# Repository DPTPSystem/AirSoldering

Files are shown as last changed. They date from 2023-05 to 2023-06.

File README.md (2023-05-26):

# AirSoldering
* Forrólevegős SMD forrasztó állomás
* DPTP System 2023-05-24.
* Projekt keletkezése: 2014-05-16.
* 4 soros karakteres kijelző, PIC18F4550 és vagy PIC18F452, K típusú hőszenzor és MAX6675 - MPLAB IDE 8.91

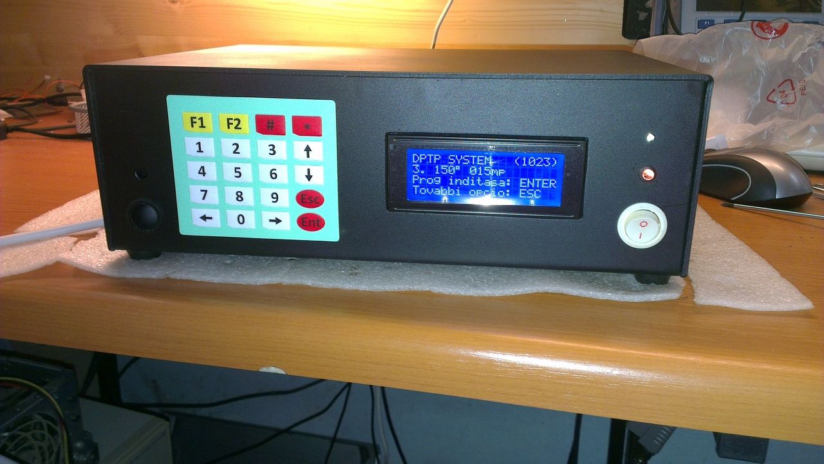
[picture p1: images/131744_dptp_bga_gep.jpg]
DPTP System BGA soldering


# A kezdet és figyelmeztetés
Anno 2014-ben kezdtem el komolyabban fogglalkozni a mikrokontrollerekkel és az azokra írható programokkal. Ezzel egyidőben az elektrokinával is 
fogglakoznom kellett mert a mikrokontrollerek önmagukban nem sokat érnek, kell egy jó elektronikai kialakítás mondhatni körítés, amely majd 
betölti azt a szerepet, amellyel a programunk képes a vezérlést elvégezni. Mivel a kezdet mindig nehéz és sok tanulással jár, sokáig nem készítettem
sematikus/kapcsolási rajzokat, szimplán elkészítettem fejből a nyáktervet és a nyáktervekre írtam fel az alkatrészek paramétereit. Amjd ezt használva
beültettem az elkészült panelekt. Ezért ez a projekt nem tartalmaz kapcsolási rajzot, viszont a nyákterven fel vannak tüntetve az alkatrészek
megnevezései. Az elkészült panel egyszerűsége olyan mértékű, hogy kis szakértelemmel nagyon könnyen át lehet látni. Kérek mindenkit, hogy ennek
tudatában álljon neki az utánépítésnek. Köszönöm.

# Miért
2005-ben megjelent Xbox360-as konzolok hirtelen, gyors és tömeges meghíbásodásai miatt, mondhatni kényszerhelyzetben egy prototípus gépen
kezdtünk el dolgozni, amely arra volt hivatott, hogy megoldja a BGA tokozott chippek házi körülmények közt történő ipari színtű javítását/cseréjét.
A BGA chippek cseréjéhez fontos volt egy alsó PCB és felső kimondottan a BGA chipekhez igazítható forrasztási mehanizmus megalkotásárára, így
született az első PID vezérlésű saját forrasztó államásunk, amellyel talán az országban elsőként kezdük el az Xbox360-as konzolok tömeges javítását.
Ezt követően a rengeteg tapsztalatra és a fejlődő tudásunkra támaszkodva készítettük el az ebben a szálban megosztott forrólevegős, hőprofilos
forrasztó berendezés terveit és programját.

# Célok
A célunk az volt, hogy a kisebb BGA tokozású, de akár SMD alkatrészeket, hőprofilt alkalmazva, optimális a lehető legkisebb hőstressz melett
legyünk képesek a javításokat elvégezni, BGA alkatrészeket cserélni. Fontos volt számunkra, hogy úgy tudjunk a javításokat végezni, hogy közben
a tapasztalatainkra tudjunk támaszkodni és ennek megfelelően a már kitesztelt és jól bevált hőprofilok mellett a lehető legkisebb károsodással
járjanak a kényes berenezések esetén is a beavatkozások.

# Elmélet a megoldás
A rendszer elméleti és egyben a megoldása is a sikeres utánépítésnek, hogy valamelyest képet alkossak arról, hogy milyen további eszközöket kell 
beszerezned, hogy megfelelő írányba indulhass el. Hogy mi a jó és mi nem azt nem akarom senkinek megírni, de hogy én milyen alkotó elemeket
használtam fel azt nyugodtan tudom leírni. 9 fő részre osztható a teljes állomás:
1. aluminium doboz, mérete függ majd a légszállítást végző ventillűtor méretétől.
2. légszállításra PWM vezérelhető 12v-os ventillátor (PS3 ventillátor, ~1.5A).
3. 3D nyomtatott vagy valamilyen kialakítással meg kell oldani a megfelelő légcsatornát
4. 4soros, karakteres kijelző HD44780
5. K-type sensor (80-100cm) vagy forrólevegős forrasztó fej, amelyben benne van a K-type szenzor
6. 12v-os kapcsolóüzemű tápegység. (fontos, hogy ipari vagy jó minőségú legyen, ne legyen zajos)
7. 4x4-es matrix gombsor, billenő bekapcsoló gomb, USB kimenet (opcionális)
8. 45A-es logikai szilárdtestrelé 600v-os (fűtőszál kapcsolgatására)
9. Buzzer (csipogó)

Elméleti működés: A gép billenő kapcsolóval felkapcsólva az előre elmentett hőprofilt betölti és várakozik a felhasználóra. A memória és a MAX6675
SPI kapcsolaton keresztül kommunikál. A memóriába összesen 15, egyenként hat lépésben megadott hőprofilt lehet elmenteni, amelyet egy menüből
később el lehet érni illetve be lehet tölteni. Minden betöltésnél automatikusan a PIC EEPROM memóriájába lementni a betöltött profil számát, amely
a memóriában lévő pozicióját határoza meg. Indulásnál ezt az EEPROM területet vizsgálja a program és ennek megfelelően tölti be az utoljára kiválasztott
profilt. Az eszközön 3 LED is található. Rendserint ezek különböző színűek, az egyik LED az üzemelést hivatott jelezni ez álltalában piros, a második
egy kék színű LED, amely a fejben lévő fűtőszál üzemidejét jelzi vissza. A harmadik LED egy villogó sárga vagy piros visszajelző a teszt vagy 
demó programot mutatja, amely majd egyszer az SMD forrasztás programmódja lesz. (egyszer)
A kezelőfelületnél mindenki eldöntheti mit mire használ, csak ebben az esetben a programban ezen részeket át kell írni, de úgy vélem a lehető 
legoptimálisabb és kézenfekvő funkciókat tettem a gombokra, amelyeket a kijelzőn jelzek is.
A MAX6675 egy K típusú szenzorhoz készült analog digitális converter, amely az alapvető kompenzációkat tartalmazza, és 12bit-es digitális jelre alakítja,
amelyekhez SPI-vel lehet hozzáférni. A PWM vezérlés a légáramlat függvényében adható meg figyelembe véve, a forrasztófejre helyzett szűktést.
A hőprofil elindulását követően 4 fontos értéket láthatunk a kijelzőn. Felüle a beállított hőmérségklet és idő látható, alattuk pedig az aktuális
adatokat írja ki. A programot bármikor meg lehet szakítani, majd azt újra indítani vagy módosítani a szerkesztés menüponton keresztül. Fontos lehet
megemlítenem, hogy a 4x4-es gombsort egy saját elképzelés alapján megírt program vezérli, amely a régi telefonoknál (NOKIA) megszokott SMS írásainál
hazsnálhattunk. Szöveg beírását követően fel fogja kínálni a lehetőségeket a program. A beírásnál elég jól sikerült behatárolnom és kitesztelnem az 
elkövethető direkt vagy véletlen hibákat, így a program majd ennek megfelelően korrígál. A megszakításokat kimértem, így az 1 másdoperc az pontosnak
nevezhető. A MAX6675 és a K-type szenzort valós körülmények közt teszteltem és ennek eredményeként és megfelelően állítottam be a szoftveres kompenzációt, 
amelyek különböző hőmérsékletek esetében más-más is lehet. Erre utóbbira külön korrekciós tálát is hoztam létre. 
A fűtőszálat egy erre alkalmas és gyors logikai szilárdtestrelével kapcsolgatom, fontos, hogy tényleg gyors legyen és a kapcsoló árama ne legyen nagyobb
egy LED-énél, vagy is 5v 15-30mA. Ha nagyobb, akkor szükséges az elektronikát egy megfelelő gyors tranzisztorral vagy FET-el kiegészíteni. Hang
visszajelzés 12v-al működik, egy tranzisztoros kapcsolással. Minden indulásnál és a menüpontok közti váltásnál illetve minden fontosabb funkciónál
visszajelzést ad az állapotról. Álltalában ezek a visszajelzések egy-egy rövidebb csippanással járnak. Úgy gondolom ennyi elég az elméletről, ha
további kérdések merülnek fel írj nyugodtan, ha időm engedi és időben észre veszem azonnal reagálok.

# Hiba
A képen egy hibás hőprofilos forrasztás következménye.:

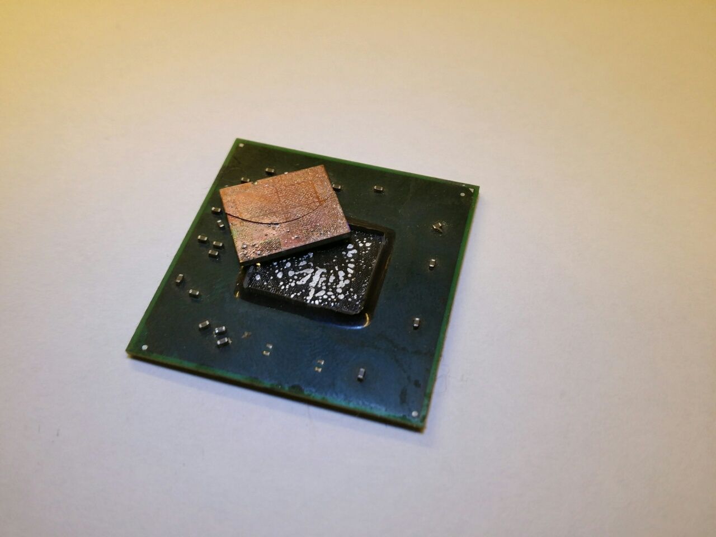
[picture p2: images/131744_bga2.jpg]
Faulty BGA soldering


# Hardver
A hardver maga nincs túl bonyolítva, összeségében egy PCB készült, amely tartalmaz minden elektronikai részt kivéve a tápegységet. A vezérlés
központjában egy (az első típusoknál) PIC18F4550-es Microchip MCU helyezkedik el (későbbi verzióknál PIC18F452-est használtam), amely kommunikál
egy 64KByte-os memóriával, egy K típusú szenzorral, egy 4x4-es gombsorral, egy karakteres kijelzővel és egy PWM vezérelt ventillátorral. 
A PCB furatszerelt egyoldalas majd később felületszerelt egyoldalas és később felületszerelt kétoldalas kivitelben készült el.

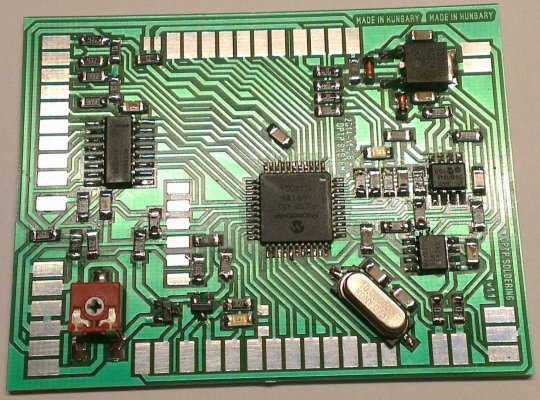
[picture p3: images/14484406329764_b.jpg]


# Nyáktervek
Furatszerelt verzió:

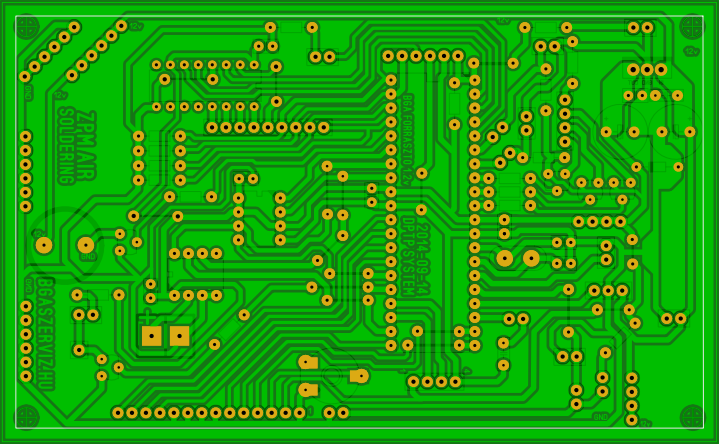
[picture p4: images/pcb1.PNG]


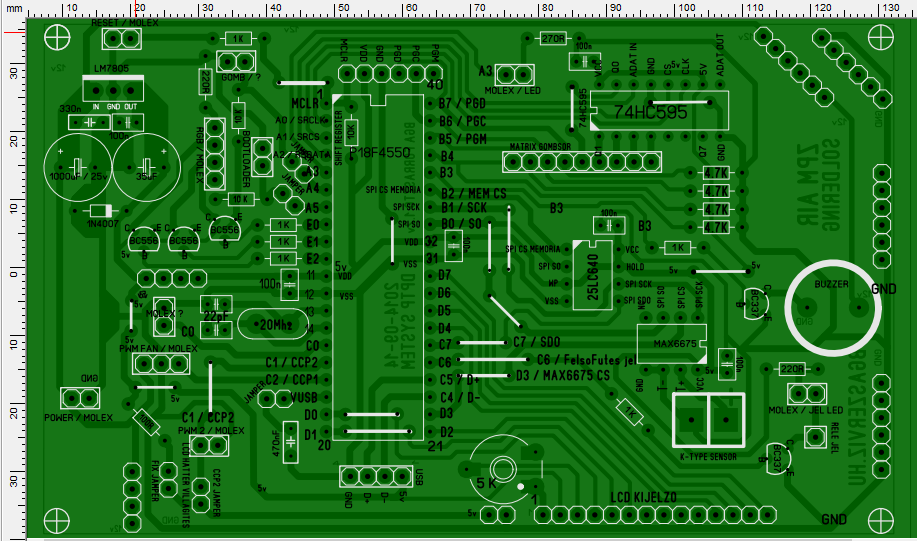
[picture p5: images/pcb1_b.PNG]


SMD változat:

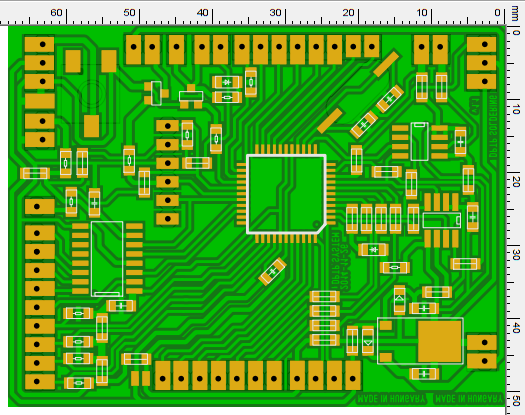
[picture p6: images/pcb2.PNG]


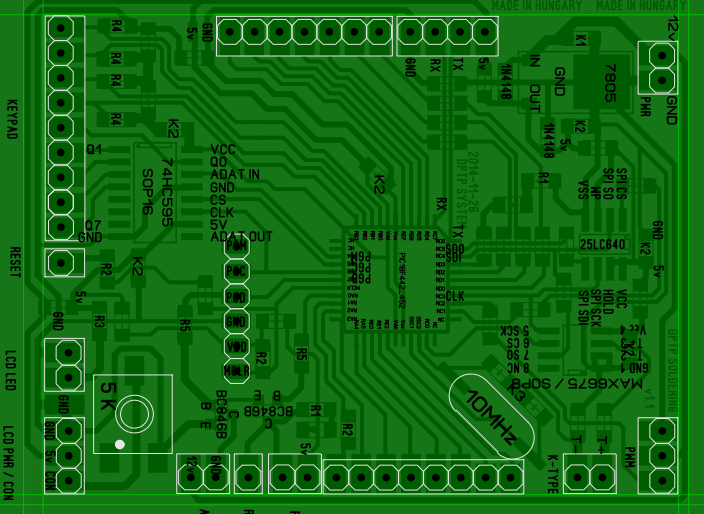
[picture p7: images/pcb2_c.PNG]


# Program
A vezérlő programja még eléggé kezdetleges, de már elég kompleksz ahhoz, hogy releváns lehessen. Képes a vezérlő elmenteni 15 előre beállított
hőprofilt, képes az utolsó beállított hőprofilt megjegyezni és a következő indulásnál vissza tölteni azt, illetve üresjáratban képesek vagyunk,
új profilt betölteni. A húprofil beállítása összesen 6 lépésből áll, amelyek a következőek:
- 6 x lépés, maximum hőmérséklet, felmelegedési várakozás / kitartás

A hőprofil illetve a forrasztási program lejártát követően a visszahűtési eljárásra vált a program, amely ~6 fok/másodperc egészen 80 fokig, 
majd ezt követően a légszállítás a legalacsonyabb fokozatba lép majd 50 fokot elérve le is áll.

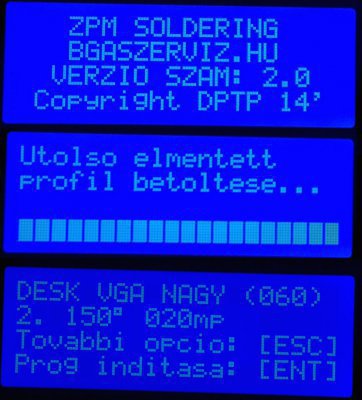
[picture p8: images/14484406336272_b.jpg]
Display


# Ahol megoldást jelentett a berendezés
Ebben a szakaszban és rövid felsorolásban néhány területet és célgépet említenék meg, ahol sikerrel tudtuk használni az elkészült gépet.
1. játék konzolok, Xbox, PS, SEGA, Nintendo, Arcade, Neo Geo és még sok más játék
2. nehéz gépek, targonca vezérlés, hasznon gépjárművek vezérlése
3. krumpli válogató gyártosori vezérlés
4. gyermekorvosi szív ultrahang és normál ultrahang gépek javítása
5. PC VGA kártyák javítása
6. Személyautók vezérlése
7. Hordozható számítógépek
8. és további BGA vagy SMD, esetenként diszkrét alaktarészekkel szerelt elektronikai berendezések javítása.

# Kapcsolodó videós tartalmak
DPTP System - PS3 ventilátor szabályozás
https://www.youtube.com/watch?v=6KxBIMjXPOY

DPTP System - Led digitális PWM vezérléssel
https://www.youtube.com/watch?v=YQ3GbyC51UQ

DPTP System - 4x4-es mátrix keypad PIC-el 
https://www.youtube.com/watch?v=JBfIr0ge0tk

DPTP System - 4x4 mátrix - PIC 
https://www.youtube.com/watch?v=hZN4geVwEG4

DPTP SYSTEM - Forrasztó vezérlő prototípus 
https://www.youtube.com/watch?v=Y2zX46Tqc7M

DPTP System - ZPM Forrasztó 
https://www.youtube.com/watch?v=1Q6x2KFnHvs

# Verseny
Tanulmányaim során volt lehetőségem versenyen is indulni, de ezen projekttel díjat nem sikerült bezsebelnem. (Korábbi évben egy kupak 
elektronikával, díjazott helyezést értem el, amelyet a muszakivagyok.hu oldalon napjainkban is el lehet érni)

DPTP System - Hőprofilos forrasztó - Működj Pályázat 2017
https://www.youtube.com/watch?v=RiwQ2Q4VDKY

# Továbbfejlesztés
A projekt elkészülte után 1 évvel további fejlesztések történtek, amelyek a készülékeket kiegészítette egy frissítési szolgáltatással, amely 
egy bootloader segítségével megoldja a már kész gépek új szoftververzióval történő frissítését, USB kábelen keresztül. A további szofveres
fejlesztések már csak akarat és idő kérdése. A gépen elkezdődőt egy SMD forrasztási mód megírása, de idő és érdeklődés hiányában ez a rész
a demón kívűl nem fejeződött be.

# Új verzió
Készült a készülékből egy komolyabb kijlezővel és új funkciókkal kibővített PIC18F46K22-es MCU-ra épített verzió, amely 80%-ban el is készült, de
az összeszerelés fázisában idő hiány miatt megrekedt. Erről az új kibővített verzióról, mivel nem készült el teljesen és nem lett tesztelve
éles helyzetben, nem osztom meg, de pár képet és videó anyagot tudok közzétenni. Az új verzió már több hőszenzort, több PWM vezérelt meghajtást,
grafikus kijelzőt és alsó IR panel vezérlést is tartalmaz, illetve további kisebb felhasználói funkciót tartalmaz.

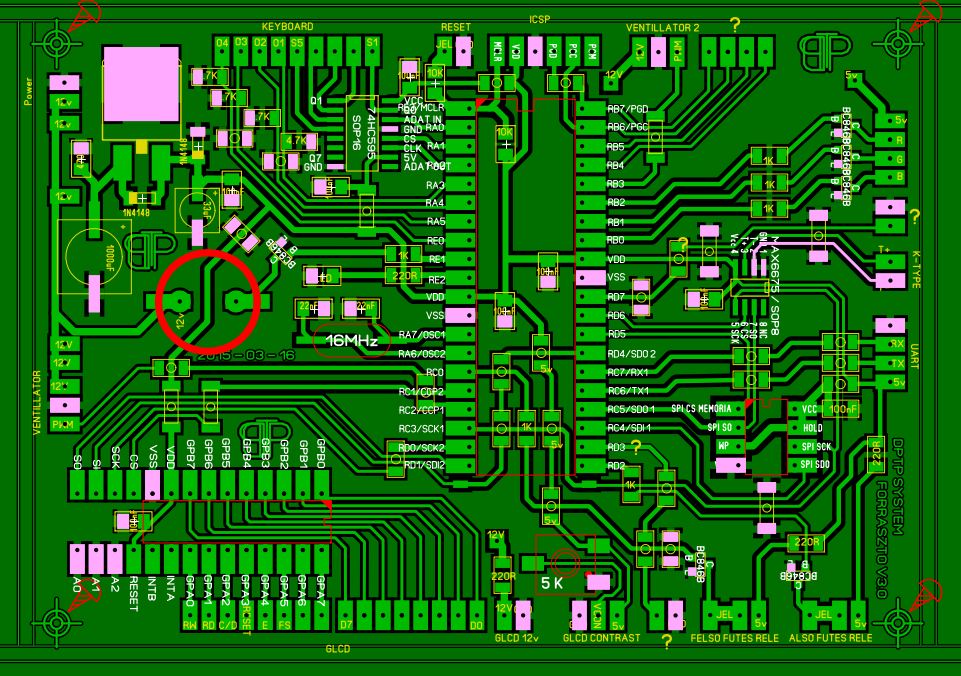
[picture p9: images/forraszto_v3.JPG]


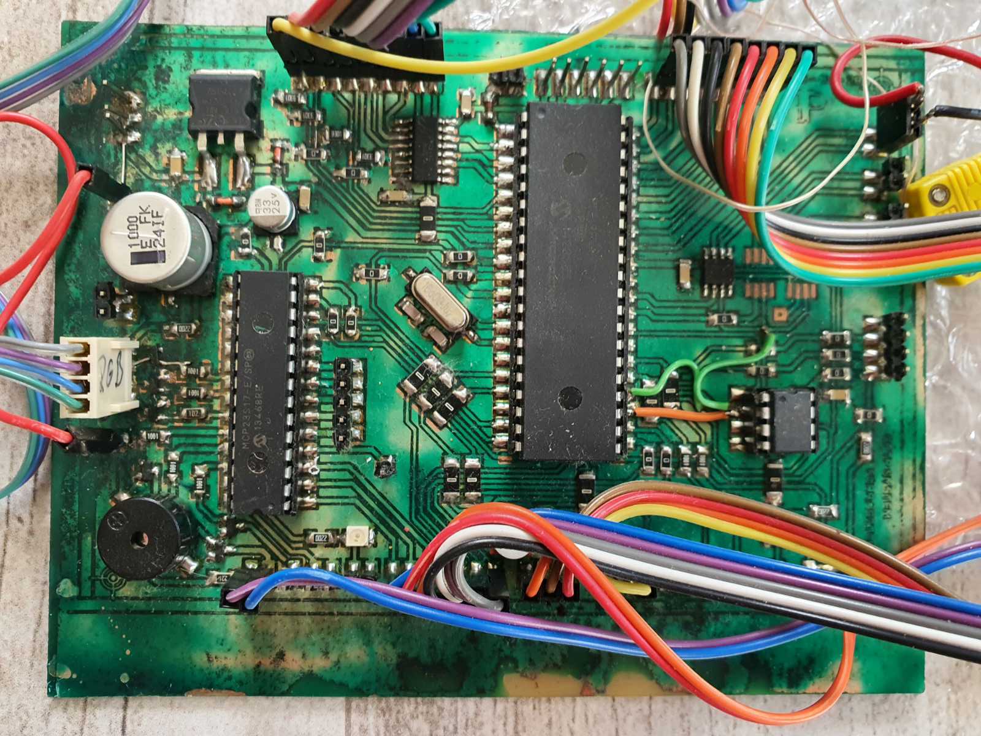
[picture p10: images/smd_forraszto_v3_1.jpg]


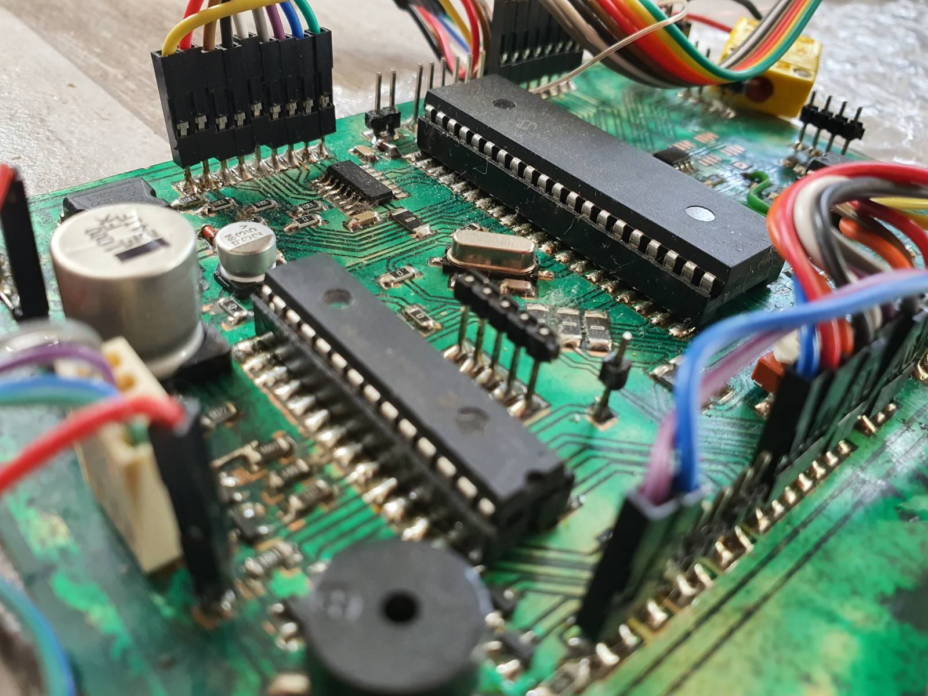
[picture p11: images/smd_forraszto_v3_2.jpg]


DPTP System - V3 Forrasztást vezérlő prototípus 
https://www.youtube.com/watch?v=cjfGa7zWkMY

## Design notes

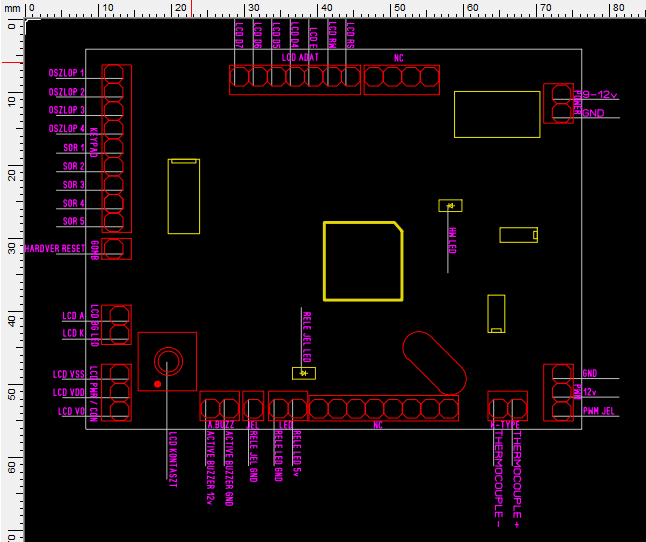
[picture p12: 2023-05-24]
images/pcb2_b.PNG

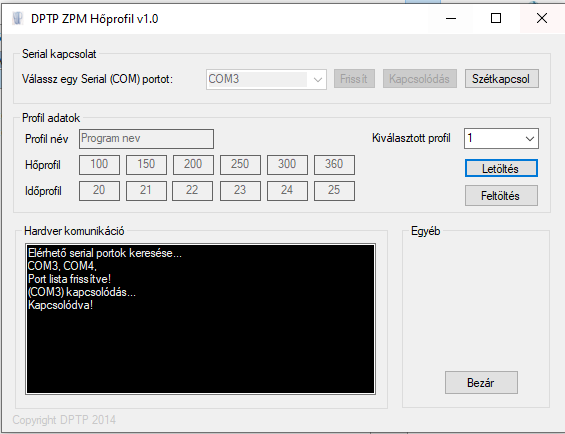
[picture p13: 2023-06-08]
images/hoprofi_pc.PNG

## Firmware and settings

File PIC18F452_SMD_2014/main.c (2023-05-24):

/************************
+ SMD DPTP SOLDERING
+ don_peter@freemail.hu
+ 2014-11-06 - Budapest
************************/

/*********************************************
+		Külsõ fájlok beemelése
**********************************************/
#include <p18F452.h>			//PIC beálltása
#include <stdio.h>
#include <delays.h>				//Késleltetések
#include <stdlib.h>
#include <timers.h>				//Timer-ek
#include <pwm.h>				//PWM fügvénykönyvtár
#include <spi.h>				//SPI fügvénykönyvtár
#include "header.h"				//Álltalános header beállítások
#include "lcd.c"				//LDC meghajtás függvényei

/*********************************************
+		Definciciók deklarálása
**********************************************/

#define SPI_CS_TRIS		TRISCbits.TRISC1	//C1 chip választás (Memória ChipSelect)
#define SPI_CS			LATCbits.LATC1		//C1 chip választás (Memória ChipSelect)
#define SPI_SO_TRIS		TRISCbits.TRISC5	//C5-ás bit
#define SPI_SCK_TRIS	TRISCbits.TRISC3	//C3-es bit órajel
#define SPI_SI			TRISCbits.TRISC4	//C4 adat ki
//----------- Max6675 vezérlõlábai -----------------------//
#define MAX1CS			LATCbits.LATC0		// MAX6675 ChipSelect láb
//----------- ShifRegiszter vezérlõlábai -----------------------//
#define SRCLK			LATBbits.LATB6
#define	SRCS			LATBbits.LATB5
#define	SRADAT			LATBbits.LATB4
#define SBIT(x){SRCS=0; SRADAT=x; SRCLK=1; SRCLK=0; SRCS=1;}
//----------- Power led vezérlõ láb -----------------------//
#define LED_P			LATDbits.LATD3		// Piros LED
//----------- BUZZER vezérlõ láb -----------------------//
#define BUZZER			LATBbits.LATB7		//Buzzer (csipogó)
//----------- Fûtõbetétek vezérlõlábai -----------------------//
#define FelsoFutesRele	LATAbits.LATA0		//Felsõ fûtés relét vezérlõ láb (A0)
//-- A 25LC640 EEPROM által elfogadott parancsok
//----------- Parancsok 25LC460 memóriához -----------------------//
#define CMD_WRSR  		0x01		//Státuszregiszter írása
#define CMD_WRITE 		0x02		//Írás a megadott címtõl kezdõdõen
#define CMD_READ  		0x03		//Olvasás a megadott címtõl kezdõdõen
#define CMD_WRDI  		0x04		//Letiltja az írást
#define CMD_RDSR  		0x05		//Státuszregiszter olvasása
#define CMD_WREN  		0x06		//Engedélyezi az írást
/*Memória blokk kiszámolása: 		1 bájt a sor érvényesítõ, (#)
									14 bájt a név,			(min 3 - max 14)
							 		12 bájt a hõprofil,		(1-500)
									6 bájt az idõprofil,	(1-255)*/
#define PCHARSIZE	14				//18 bájt profil unsigned char buffer (8bit)
#define PINTSIZE	12				//18 bájt profil short int buffer (16bit)
#define PMEMBLOCK	32				//Profil memória block (32bájt)
#define PPROGSZAM	15				//Megengedett profilok száma (32bájt x 15 == 480bájt)
//------------------------------ 4x4 MATRIX -----------------------------------//
//#define SOROK 			LATA 		//Sorok 4x4 matrix
#define oszlop1 		PORTBbits.RB0 	//Oszlopok bemenetek 4x4 matrix
#define oszlop2 		PORTBbits.RB1	//-"-
#define oszlop3 		PORTBbits.RB2	//-"-
#define oszlop4 		PORTBbits.RB3	//-"-
#define KeyNumeric		0			//Csak numerikus gombok engedélyezése
#define KeyAlfanum		1			//Alfanumerikus gombok engedélyezése
#define Cursors			10			//Kursor villogásának gyakorisága
#define WhileTime		20			//While ciklus azonos idõzítése (miliszekondumban)
#define AtlagTMeret		4			//Átlagoló buffer tömb mérete
/*********************************************
+		Globális változók deklarálása
**********************************************/
//----------- Profil adatok tárolása -----------------// 
unsigned char 	ERVPROFCHAR[PCHARSIZE+1] = {0};				//8bites adatok (#név)
short int 		ERVPROFINT[PINTSIZE+1] = {0};				//16bites adatok
//----------- Program futása közbeni adatok ------------//
unsigned char Tido;											//timer0 idõ méréséhez
unsigned char Timer0Count;									//timer0 számolása
unsigned char Hofoklepes;									//Hõfokot léptetjük globálisan a timer0 miatt
unsigned short int HoBufferTomb[AtlagTMeret+1] = {0};	//Hõmérsékleteket fogja tárolni az átlagoláshoz
unsigned char AtlagBTCount = 0;								//Átlagoló tömb számoló
//----------- 4x4 MATRIX változók -----------------//
unsigned char Navigacio;									//Navigacios változó (0-9)

/*********************************************
+		Külsõ fájlok beemelése 2 (ide kerülnek azon fájlok melyek definiciókat vagy globális változókat használnak)
**********************************************/
#include "init.c"				//Fontosabb függvények egy csoportba
#include "fuggvenyek.c"			//Függvény könyvtár
#include "interrupt.c"			//Megszaktások függvényei
	
void main(void){
	
	/*********************************************
	+		Változók deklarálása
	**********************************************/	
	union16 MemCim, ReadCim;					//16bit-es struct változók
	unsigned char Membuffer[PMEMBLOCK+1] = {0}; //Profil blokk buffer
	
	unsigned char ciklus = 0;
	
	init();
	
	/*while(1){
		printf("K-type Sensor       ");
		lcd_write(0xC0,0,1,1);   
		printf("%i                  ", Max6675());
		lcd_write(0x94,0,1,1);
		printf("                    ");
		lcd_write(0xD4,0,1,1);
		printf("Ciklus: %i          ", ciklus);
		lcd_write(0x80,0,1,1);
		LED_P = !LED_P;
		Delay_ms(255);
	ciklus++;
	}*/


	RomStringWrite(szovegek[14]);
	lcd_write(0xC0,0,1,1);   
	RomStringWrite(szovegek[15]);
	lcd_write(0x94,0,1,1);
	RomStringWrite(szovegek[16]);
	lcd_write(0xD4,0,1,1);
	RomStringWrite(szovegek[17]);
	lcd_write(0x80,0,1,1); 
	Buzzer(1, 100);
	Delay_ms(1000*5);	//kb ~5mp
	
	lcd_clear();	//Töröljük az LCD kijelzõt
		
	//Beolvassuk az Eeprom elsõ 1 bájt-ját ami tárolja az utolsó elmentett profil számát (1-15)
	if((int)EepromRead()>0 && (int)EepromRead()<=PPROGSZAM){
		if(profilok_szama(EepromRead())){
			profilt_betolt(EepromRead());	//Betöltjük az elmentett profilt
			
			RomStringWrite(szovegek[18]);
			lcd_write(0xC0,0,1,1);   
			RomStringWrite(szovegek[19]);
			lcd_write(0x94,0,1,1);
			RomStringWrite(szovegek[20]);
			lcd_write(0xD4,0,1,1);
			betoltes();
			lcd_write(0x80,0,1,1);
			Delay_ms(500);	//Várunk ~2mp-et
		
			Navigacio=1;
		}else{
			//Ha nincs érvényes adat a memória címen hibával térünk vissza
			RomStringWrite(szovegek[21]);
			lcd_write(0xC0,0,1,1);   
			RomStringWrite(szovegek[22]);
			lcd_write(0x94,0,1,1);
			RomStringWrite(szovegek[20]);
			lcd_write(0xD4,0,1,1);
			RomStringWrite(szovegek[20]);
			lcd_write(0x80,0,1,1);
			Delay_ms(1000*2);	//Várunk ~2mp-et
			
			Navigacio=0;
		}
	}else{
		//Ha még nem történ mentés az Eepromba (elsõ indítás vagy hiba esetén fórdul elõ)
		RomStringWrite(szovegek[23]);
		lcd_write(0xC0,0,1,1);   
		RomStringWrite(szovegek[24]);
		lcd_write(0x94,0,1,1);
		RomStringWrite(szovegek[20]);
		lcd_write(0xD4,0,1,1);
		RomStringWrite(szovegek[20]);
		lcd_write(0x80,0,1,1);
		Delay_ms(1000*2);	//Várunk ~2mp-et

		Navigacio=0;
	}
	while(1){
		if(Navigacio==1){	//Profil betöltve == 1
			if(profilok_szama(EepromRead())!=0){
				profilt_mutat();
			}else{
				RomStringWrite(szovegek[25]);
				lcd_write(0xC0,0,1,1);   
				RomStringWrite(szovegek[26]);
				lcd_write(0x94,0,1,1);
				RomStringWrite(szovegek[20]);
				lcd_write(0xD4,0,1,1);
				RomStringWrite(szovegek[20]);
				lcd_write(0x80,0,1,1);
				Delay_ms(1000*2);

				Navigacio=0;
			}
		}else if(Navigacio==0){	//Menü == 0
			LED_P = 0;	//Piros LED tiltása
			HighInterruptIni();	// Magas piorítású interrupt engedélyezése
			menu();
		}else if(Navigacio==2){	//Új profil felvétele
			if(profilok_szama(0)<PPROGSZAM){
				uj_profil(0);
			}else{
				RomStringWrite(szovegek[27]);
				lcd_write(0xC0,0,1,1);   
				RomStringWrite(szovegek[28]);
				lcd_write(0x94,0,1,1);
				RomStringWrite(szovegek[20]);
				lcd_write(0xD4,0,1,1);
				RomStringWrite(szovegek[20]);
				lcd_write(0x80,0,1,1);
				Delay_ms(1000*2);
			}
		}else if(Navigacio==3){	//Profil szerkesztése
			uj_profil(1);
		}else if(Navigacio==4){	//Profilok listája
			profil_lista();
		}else if(Navigacio==5){	//Start
			start();
		}else if(Navigacio==6){	//Stop
			stop();
		}else if(Navigacio==7){	//SMD forrasztó
			SMD_forraszto();
		}
		
	}//while()

}//main

/***********************************
+			Hõfok teszt			   +
***********************************/
/*
Víz:			Forrasztó páka		SMD Forrasztó		Forrasztó páka	-	KID-R480A
0	==	0
				50	==	84								50					89
100	==	100		100	==	134			100	==	130			100					144
				150	==	185			150	==	185			150					190
				200	==	224			200	==	234			200					237
				250	==	264			250	==	284			250					282
				300	==	300			300	==	335			300					324
				350	==	337			350	==	384			350					360
				400	==	374			400	==	444			400					400
				422	==	384			450	==	504			422					---
									480	==	534
*/

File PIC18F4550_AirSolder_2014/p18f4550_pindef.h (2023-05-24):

/**************************************************************************
A port definiciója
**************************************************************************/
/*TRISA*/
#define TRIS_A0		TRISAbits.TRISA0 //2-láb
#define TRIS_A1		TRISAbits.TRISA1 //3.láb
#define TRIS_A2		TRISAbits.TRISA2 //4.láb
#define TRIS_A3		TRISAbits.TRISA3 //5.láb
#define TRIS_A4		TRISAbits.TRISA4 //6.láb
#define TRIS_A5		TRISAbits.TRISA5 //7-láb
//#define TRIS_A6		TRISAbits.TRISA6 //14.láb OSC 1 (kirstály) 
//#define TRIS_A7		TRISAbits.TRISA7 //13.láb OSC 2 (kristály)

/*PORTA*/
#define PORT_A0		PORTAbits.RA0 //2-láb
#define PORT_A1		PORTAbits.RA1 //3.láb
#define PORT_A2		PORTAbits.RA2 //4.láb
#define PORT_A3		PORTAbits.RA3 //5.láb
#define PORT_A4		PORTAbits.RA4 //6.láb
#define PORT_A5		PORTAbits.RA5 //7-láb
//#define PORT_A6		PORTAbits.RA6 //14.láb OSC 1 (kirstály) 
//#define PORT_A7		PORTAbits.RA7 //13.láb OSC 2 (kristály)

/*LATA*/
#define LAT_A0		LATAbits.LATA0 //2-láb
#define LAT_A1		LATAbits.LATA1 //3.láb
#define LAT_A2		LATAbits.LATA2 //4.láb
#define LAT_A3		LATAbits.LATA3 //5.láb
#define LAT_A4		LATAbits.LATA4 //6.láb
#define LAT_A5		LATAbits.LATA5 //7-láb
//#define LAT_A6		LATAbits.LATA6 //14.láb OSC 1 (kirstály) 
//#define LAT_A7		LATAbits.LATA7 //13.láb OSC 2 (kristály)

/**************************************************************************
B port definiciója
**************************************************************************/
/*TRISB*/
#define TRIS_B0		TRISBbits.TRISB0 //33.láb
#define TRIS_B1		TRISBbits.TRISB1 //34.láb
#define TRIS_B2		TRISBbits.TRISB2 //35.láb
#define TRIS_B3		TRISBbits.TRISB3 //36.láb
#define TRIS_B4		TRISBbits.TRISB4 //37.láb
#define TRIS_B5		TRISBbits.TRISB5 //38.láb
#define TRIS_B6		TRISBbits.TRISB6 //39.láb
#define TRIS_B7		TRISBbits.TRISB7 //40.láb

/*PORTB*/
#define PORT_B0		PORTBbits.RB0 //33.láb
#define PORT_B1		PORTBbits.RB1 //34.láb
#define PORT_B2		PORTBbits.RB2 //35.láb
#define PORT_B3		PORTBbits.RB3 //36.láb
#define PORT_B4		PORTBbits.RB4 //37.láb
#define PORT_B5		PORTBbits.RB5 //38.láb
#define PORT_B6		PORTBbits.RB6 //39.láb
#define PORT_B7		PORTBbits.RB7 //40.láb

/*LATB*/
#define LAT_B0		LATBbits.LATB0 //33.láb
#define LAT_B1		LATBbits.LATB1 //34.láb
#define LAT_B2		LATBbits.LATB2 //35.láb
#define LAT_B3		LATBbits.LATB3 //36.láb
#define LAT_B4		LATBbits.LATB4 //37.láb
#define LAT_B5		LATBbits.LATB5 //38.láb
#define LAT_B6		LATBbits.LATB6 //39.láb
#define LAT_B7		LATBbits.LATB7 //40.láb

/**************************************************************************
C port definiciója
**************************************************************************/
/*TRISC*/
#define TRIS_C0		TRISCbits.TRISC0 //15.láb LCD RS
#define TRIS_C1		TRISCbits.TRISC1 //16.láb LCD RW
#define TRIS_C2		TRISCbits.TRISC2 //17.láb LCD E
#define TRIS_C3		TRISCbits.TRISC3 //18.láb VUSB
#define TRIS_C4		TRISCbits.TRISC4 //23.láb
#define TRIS_C5		TRISCbits.TRISC5 //24.láb
#define TRIS_C6		TRISCbits.TRISC6 //25.láb
#define TRIS_C7		TRISCbits.TRISC7 //26.láb

/*PORTC*/
#define PORT_C0		PORTCbits.RC0 //15.láb LCD RS
#define PORT_C1		PORTCbits.RC1 //16.láb LCD RW
#define PORT_C2		PORTCbits.RC2 //17.láb LCD E
#define PORT_C3		PORTCbits.RC3 //18.láb VUSB
#define PORT_C4		PORTCbits.RC4 //23.láb
#define PORT_C5		PORTCbits.RC5 //24.láb
#define PORT_C6		PORTCbits.RC6 //25.láb
#define PORT_C7		PORTCbits.RC7 //26.láb

/*LATC*/
#define LAT_C0		LATCbits.LATC0 //15.láb LCD RS
#define LAT_C1		LATCbits.LATC1 //16.láb LCD RW
#define LAT_C2		LATCbits.LATC2 //17.láb LCD E
#define LAT_C3		LATCbits.LATC3 //18.láb VUSB
#define LAT_C4		LATCbits.LATC4 //23.láb
#define LAT_C5		LATCbits.LATC5 //24.láb
#define LAT_C6		LATCbits.LATC6 //25.láb
#define LAT_C7		LATCbits.LATC7 //26.láb

/**************************************************************************
D port definiciója
**************************************************************************/
/*TRISD*/
#define TRIS_D0		TRISDbits.TRISD0 //19.láb
#define TRIS_D1		TRISDbits.TRISD1 //20.láb
#define TRIS_D2		TRISDbits.TRISD2 //21.láb
#define TRIS_D3		TRISDbits.TRISD3 //22.láb
#define TRIS_D4		TRISDbits.TRISD4 //27.láb LCD DATA
#define TRIS_D5		TRISDbits.TRISD5 //28.láb LCD DATA
#define TRIS_D6		TRISDbits.TRISD6 //29.láb LCD DATA
#define TRIS_D7		TRISDbits.TRISD7 //30.láb LCD DATA

/*PORTD*/
#define PORT_D0		PORTDbits.RD0 //19.láb
#define PORT_D1		PORTDbits.RD1 //20.láb
#define PORT_D2		PORTDbits.RD2 //21.láb
#define PORT_D3		PORTDbits.RD3 //22.láb
#define PORT_D4		PORTDbits.RD4 //27.láb LCD DATA
#define PORT_D5		PORTDbits.RD5 //28.láb LCD DATA
#define PORT_D6		PORTDbits.RD6 //29.láb LCD DATA
#define PORT_D7		PORTDbits.RD7 //30.láb LCD DATA
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

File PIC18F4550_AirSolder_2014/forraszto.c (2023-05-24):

/*********************************************
+		PIC18F4550 Lábkiosztás
+		DPTP SYSTEM 2014-05-16
+		TÓTH PÉTER (don_peter@freemail.hu)
**********************************************
		A PORT
A0	-->		4x4 matrik sorok 1 (kimenet)
A1	-->		4x4 matrik sorok 2 (kimenet)
A2	-->		4x4 matrik sorok 3 (kimenet)
A3	-->		4x4 matrik sorok 4 (kimenet)
A4	-->		NC
A5	-->		NC
A6	-->		Kristály
A7	-->		Kristály

		B PORT
B0	-->		SPI SO
B1	-->		SPI SCK
B2	-->		Memória ChipSelect (25LC640)
B3	-->		NC
B4	-->		4x4 matrik sorok 1 (bemenet)
B5	-->		4x4 matrik sorok 2 (bemenet)
B6	-->		4x4 matrik sorok 3 (bemenet)
B7	-->		4x4 matrik sorok 4 (bemenet)

		C PORT
C0	-->		Alsó fûtés relé
C1	-->		PWM 2
C2	-->		PWM 1 PS3 ventillátor meghajtás
C3	-->		VUSB (nem használható)
C4	-->		USB D- (nem használható)
C5	-->		USB D+ (nem használható)
C6	-->		Felsõ fûtés relé
C7	-->		SPI SDO

		D PORT
D0	-->		LCD1
D1	-->		LCD2
D2	-->		LCD3
D3	-->		NC
D4	-->		LCD4
D5	-->		LCD5
D6	-->		LCD6
D7	-->		LCD7

		E PORT
E0	-->		MAX6675 1 ChipSelect
E1	-->		MAX6675 2 ChipSelect
E2	-->		MAX6675 3 ChipSelect
E3	-->		VDD 5v

/*********************************************
+		Külsõ fájlok beemelése
**********************************************/
#include <p18F4550.h>			//PIC beálltása
#include <adc.h>				//Analog függvénykönyvtár
#include <stdio.h>
#include <delays.h>				//Késleltetések
#include <stdlib.h>
#include <timers.h>				//Timer-ek
#include <pwm.h>				//PWM fügvénykönyvtár
#include <spi.h>				//SPI fügvénykönyvtár
#include "header.h"				//Álltalános header beállítások
#include "p18f4550_pindef.h"	//P18F4550 saját definicióim
#include "lcd.c"				//LDC meghajtás függvényei

/*********************************************
+		Definciciók deklarálása
**********************************************/
//-------------------------- Definciciók ----------------------------//
//PIC18F4550 SPI lábkiosztása
//7. (RA5)[SS - SPI másodlagos input választó]
//33.(RBO)[SDI - SPI adat bemenet]
//34.(RB1)[SCK - szinkron óra be/ki SPI módban]
//26.(RC7)[SDO - SPI adat kimenet]
#define SPI_CS_TRIS		TRIS_B2		//B2 chip választás (Memória ChipSelect)
#define SPI_CS			LAT_B2		//B2 chip választás (Memória ChipSelect)
#define SPI_SO_TRIS		TRIS_B0		//B0-ás bit
#define SPI_SCK_TRIS	TRIS_B1		//B1-es bit órajel
#define SPI_SI			TRIS_C7		//C7 adat ki
//--	MAX 6675 --//
/***************************************************************************************
PIC18F4550 SPI lábkiosztása MAX6675-ös chip-re
7. (RE0:RE2)[SS - SPI másodlagos input választó]	->	MAX6675 6.láb (CS) [Chip választás]
33.(RBO)[SDI - SPI adat bemenet]					->	MAX6675 7.láb (SO) [Adat kimenet]
34.(RB1)[SCK - szinkor óra be/ki SPI módban]		->	MAX6675 5.láb (SCK)[Óra bemenet]
26.(RC7)[SDO - SPI adat kimenet]
*****************************************************************************************/
#define MAX1CS			LAT_E0		//MAX6675 1. chipselect láb
#define MAX2CS			LAT_E1		//MAX6675 2. chipselect láb (Felsõ fûtést mérõ pont)
#define MAX3CS			LAT_E2		//MAX6675 3. chipselect láb
//----------- Fûtõbetétek vezérlõlábai -----------------------//
#define AlsoFutesRele	LAT_C0		//Alsó fûtés relét vezérlõ láb (C0)
#define FelsoFutesRele	LAT_D3		//Felsõ fûtés relét vezérlõ láb (C6)
//-- A 25LC640 EEPROM által elfogadott parancsok
//----------- Parancsok 25LC460 memóriához -----------------------//
//Parancs	Bináris		Hexa		Lerás
//READ 		0000 0011 	0x03		A memória olvasása adott címtõl kezdõdõen
//WRITE 	0000 0010 	0x02		A memória írása adott címtõl kezdõdõen
//WREN 		0000 0110 	0x06		Az írást engedélyezõ bit törlése (letiltja az írást)
//WRDI 		0000 0100 	0x04		Az írást engedélyezõ bit beállítása (engedélyezi az írást)
//RDSR 		0000 0101 	0x05		STATUS register olvasása
//WRSR 		0000 0001 	0x01		STATUS register írása
#define CMD_WRSR  		0x01		//Státuszregiszter írása
#define CMD_WRITE 		0x02		//Írás a megadott címtõl kezdõdõen
#define CMD_READ  		0x03		//Olvasás a megadott címtõl kezdõdõen
#define CMD_WRDI  		0x04		//Letiltja az írást
#define CMD_RDSR  		0x05		//Státuszregiszter olvasása
#define CMD_WREN  		0x06		//Engedélyezi az írást
/*Memória blokk kiszámolása: 	1 bájt a sor érvényesítõ, (#)
								17 bájt a név,			(min 3 - max 17)
							 	6 bájt a hõprofil,		(1-255)
								6 bájt az idõprofil,	(1-255)
								2 bájt az alsó fûtés	(1-1023)*/
#define PCHARSIZE	18			//18 bájt profil unsigned char buffer (8bit)
#define PINTSIZE	13			//14 bájt profil short int buffer (16bit)
#define PMEMBLOCK	32			//Profil memória block (32bájt)
#define PPROGSZAM	15			//Megengedett profilok száma (32bájt x 15 == 480bájt)
//------------------------------ 4x4 MATRIX -----------------------------------//
#define SOROK 			LATA 		//Sorok 4x4 matrix
#define oszlop1 		PORT_B4 	//Oszlopok bemenetek 4x4 matrix
#define oszlop2 		PORT_B5		//-"-
#define oszlop3 		PORT_B6		//-"-
#define oszlop4 		PORT_B7		//-"-
#define KeyNumeric		0			//Csak numerikus gombok engedélyezése
#define KeyAlfanum		1			//Alfanumerikus gombok engedélyezése
#define Cursors			20			//Kursor villogásának gyakorisága
#define AtlagTMeret		4			//Átlagoló buffer tömb mérete

/*********************************************
+		Globális változók deklarálása
**********************************************/
//----------- Profil adatok tárolása -----------------// 
unsigned char 	ERVPROFCHAR[PCHARSIZE+1] = {0};		//8bites adatok (#név)
short int 		ERVPROFINT[PINTSIZE+1] = {0};		//16bites adatok
//----------- Program futása közbeni adatok ------------//
unsigned char Tido;									//timer0 idõ méréséhez
unsigned char Hofoklepes;							//Hõfokot léptetjük globálisan a timer0 miatt
short int	  HoBufferTomb[AtlagTMeret];			//Hõmérsékleteket fogja tárolni az átlagoláshoz
unsigned char AtlagBTCount = 0;						//Átlagoló tömb számoló
//----------- 4x4 MATRIX változók -----------------//
unsigned char Navigacio;							//Navigacios változó (0-9)

/*********************************************
+		Külsõ fájlok beemelése 2 (ide kerülnek azon fájlok melyek definiciókat vagy globális változókat használnak)
**********************************************/
#include "init.c"				//Fontosabb függvények egy csoportba
#include "fuggvenyek.c"			//Függvény könyvtár
#include "interrupt.c"			//Megszaktások függvényei
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
